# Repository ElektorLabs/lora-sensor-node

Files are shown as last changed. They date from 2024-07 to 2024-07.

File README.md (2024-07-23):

# Solar Powered LoRaWAN Sensor Node

## Overview

This project is a solar-powered LoRaWAN sensor node designed to monitor environmental conditions such as soil moisture, temperature, humidity, and CO2 levels. The node transmits data via LoRaWAN to The Things Network (TTN), and the data can be visualized using platforms like DataCake and Home Assistant.

## Repository Structure

- **src**: Contains the source code for the sensor node.
- **hardware**: Contains the schematic of the project along with CAD STL files for the Solar Panel and Component Enclosure and the Stevenson Enclosure for the SCD30 Sensor.

## Libraries Used

The following libraries, are used in this project:
- `SCD30` by [Seeed Studio](https://github.com/Seeed-Studio/Seeed_SCD30) 
- `HardwareSerial` - Built in Libaray

## Setup

### 1. Hardware Setup
- Assemble the hardware components as per the schematic provided in the hardware folder.
- Use the CAD STL files to 3D print the enclosures for the solar panel, component, and Stevenson enclosure for the SCD30 sensor. (Recommended 3D Printing Filament : PETG)

### 2. Software Setup
- Open the code from the `src` folder in your Arduino IDE.
- Configure the necessary parameters, such as the App Key, in the code.
- Upload the code to the SeeedStudio XIAO ESP32-C3 microcontroller.

### 3. Integrate with The Things Network (TTN)
- Register your device on the TTN console and obtain the necessary credentials (Device EUI, Application EUI, and App Key).
- Configure the payload format to match the data structure sent by the sensor node.
- Add a webhook for DataCake integration to visualize the data.
- You have to also add the custom javascript format for decoding the HEX code sent from the LoRa Device on to your TTN and DataCake Dashboard: 

```js
function Decoder(bytes, port) {
  var decoded = {};
  if (port === 8) {
    decoded.soilMoisture = (bytes[0] << 8) | bytes[1];
    decoded.temp = ((bytes[2] << 8) | bytes[3]);
    decoded.humi = (bytes[4] << 8) | bytes[5];
    decoded.co2 = (bytes[6] << 8) | bytes[7];
    decoded.battery = (bytes[8] << 8) | bytes[9];
  }
  return decoded;
}
```

### 4. Integrate with Home Assistant
- Generate an API Key in the TTN console.
- Add "The Things Network" integration in Home Assistant and enter the necessary credentials.
- Configure the sensor entities in the `configuration.yaml` file to define the units of measurement:

  ```yaml
  sensor.lora_sense_node_temperature:
    unit_of_measurement: "°C"
  sensor.lora_sense_node_co2:
    unit_of_measurement: "ppm"
  sensor.lora_sense_node_humidity:
    unit_of_measurement: "%"
  sensor.lora_sense_node_soilmoisture:
    unit_of_measurement: "%"
  ```

## Future Improvements

Future improvements to this project could include integrating an external RTC with a power latch circuit to reduce idle power consumption. Additionally, more sensors can be added to extend the functionality of the sensor node for various applications.

## License

This project is licensed under the MIT License - see the [LICENSE](LICENSE) file for details.

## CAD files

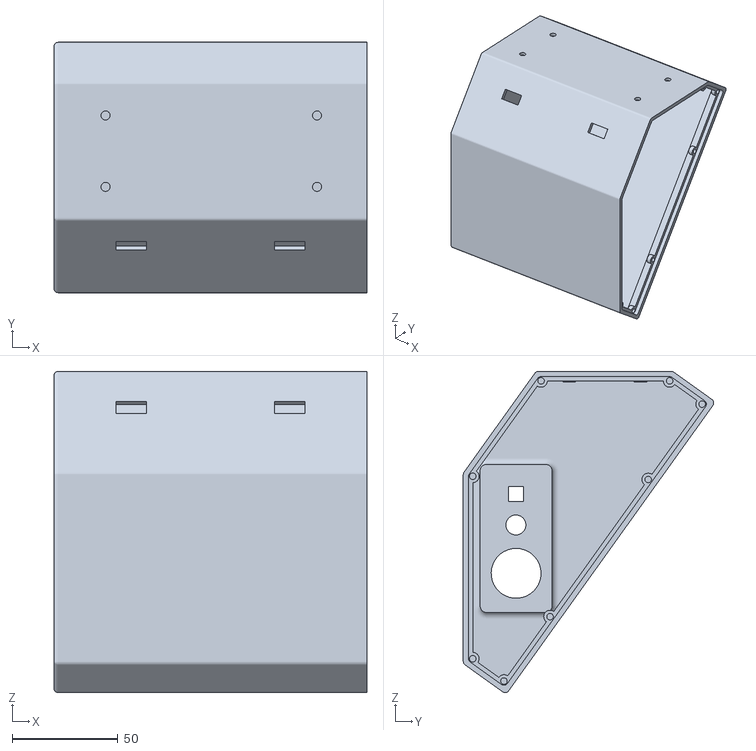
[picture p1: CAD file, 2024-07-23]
hardware/solarpanel holder enclosure/stl/asm_enclosure - enclosure_main-1-1.STL
148.0 x 118.5 x 151.9

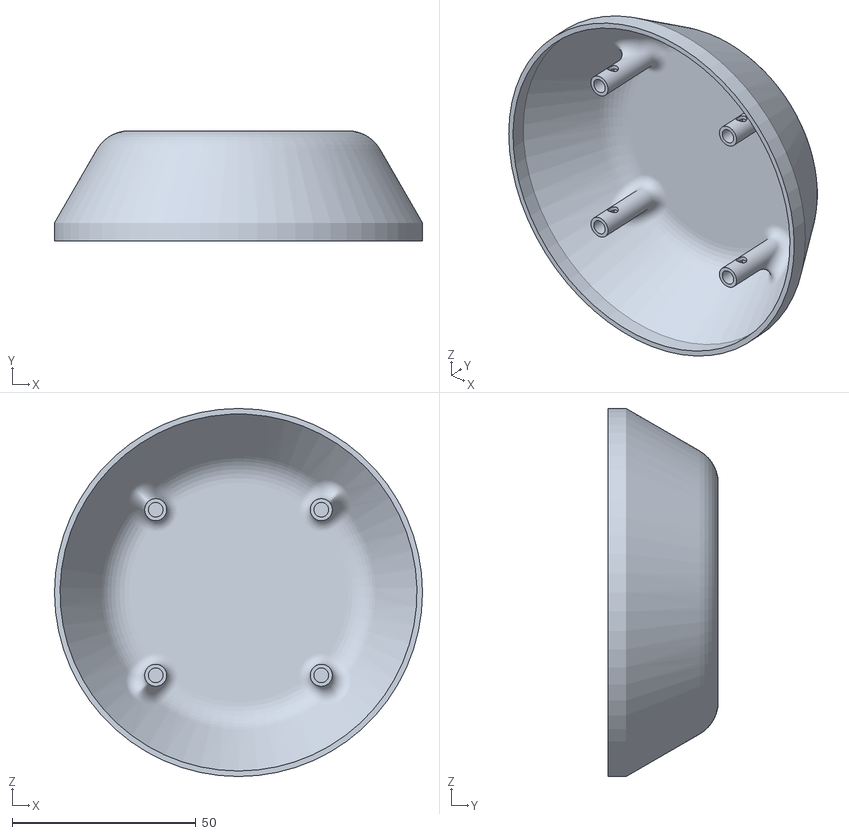
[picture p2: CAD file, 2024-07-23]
hardware/stevenson screen/stl/asm_stevemson-screen - TopCover-1.STL
100.0 x 30.0 x 100.0

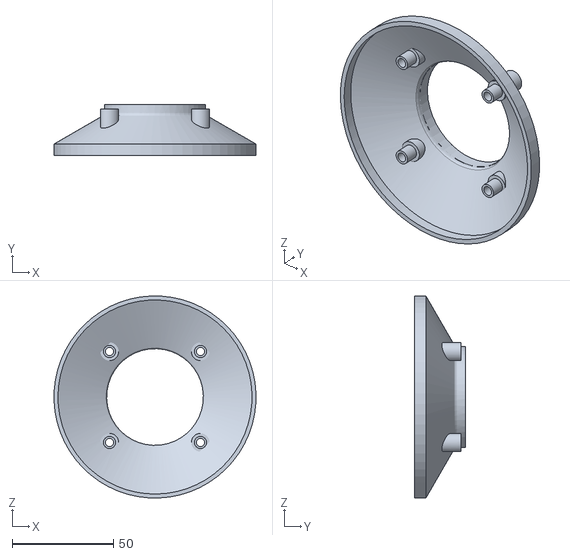
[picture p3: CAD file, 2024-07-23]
hardware/stevenson screen/stl/asm_stevemson-screen - Middle-5.STL
99.9 x 25.0 x 99.9

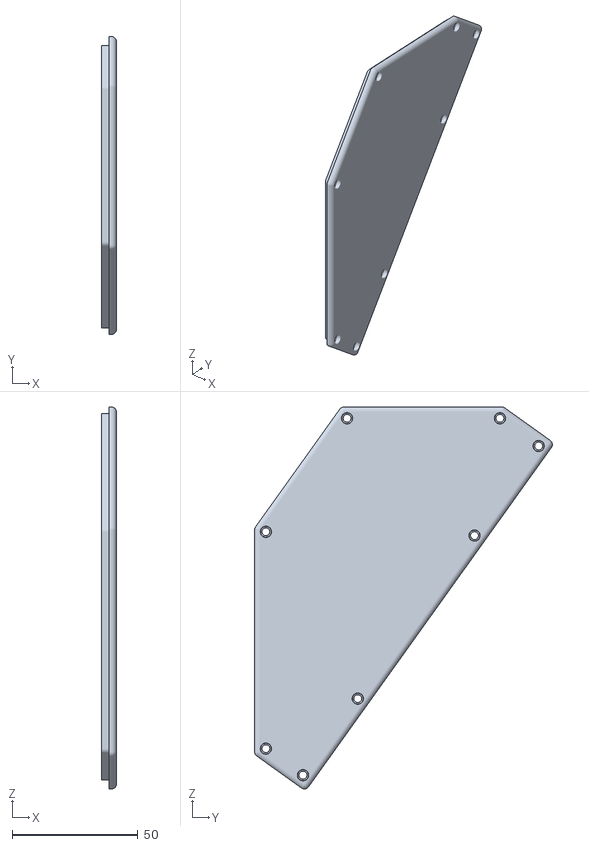
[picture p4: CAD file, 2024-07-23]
hardware/solarpanel holder enclosure/stl/asm_enclosure - side_panel-1-1.STL
6.00 x 118.5 x 151.9

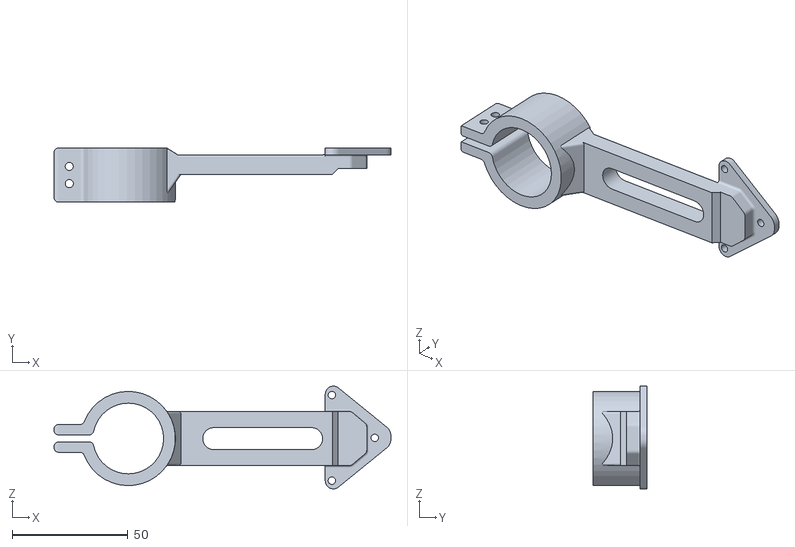
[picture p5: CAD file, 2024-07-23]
hardware/stevenson screen/stl/asm_stevemson-screen - mount_holder-1.STL
145.3 x 23.4 x 44.3

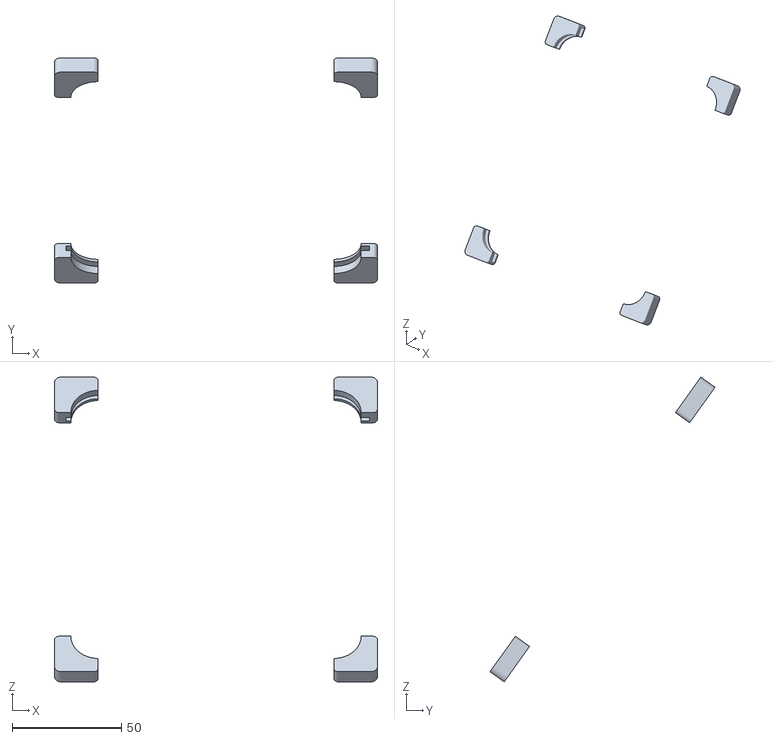
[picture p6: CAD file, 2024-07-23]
hardware/solarpanel holder enclosure/stl/asm_enclosure - solarpanel-holders-1-1.STL
148.0 x 103.1 x 139.6

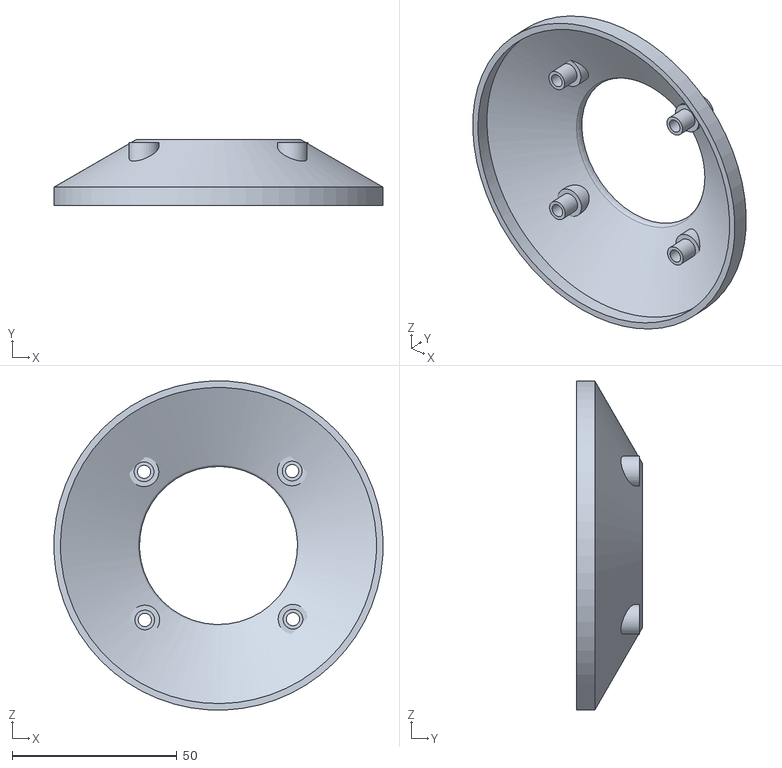
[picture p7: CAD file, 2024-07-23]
hardware/stevenson screen/stl/asm_stevemson-screen - bottom-1.STL
99.9 x 20.0 x 99.9

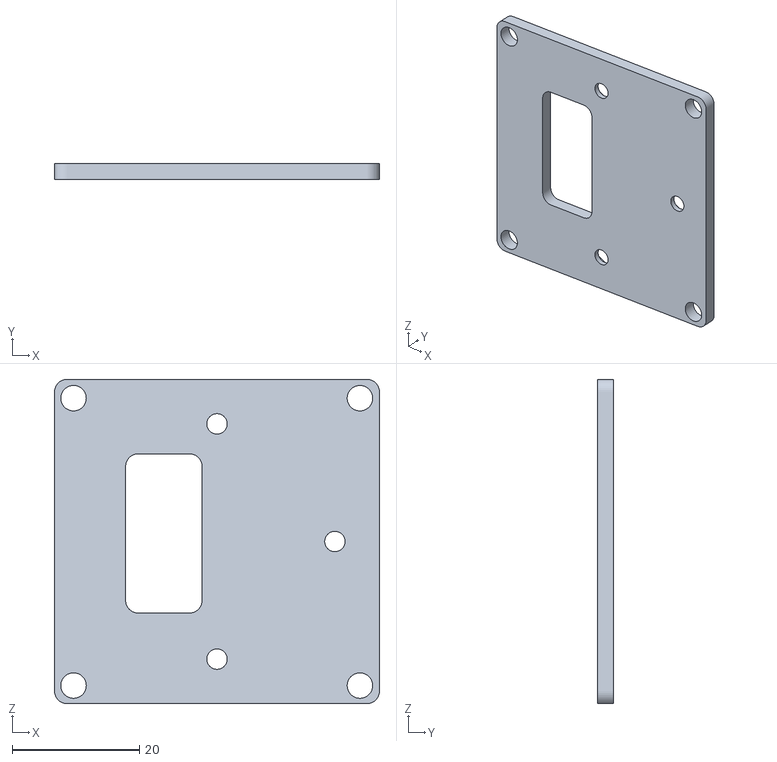
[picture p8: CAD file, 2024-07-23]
hardware/stevenson screen/stl/asm_stevemson-screen - Bottom Mount-1.STL
51.0 x 2.50 x 50.9

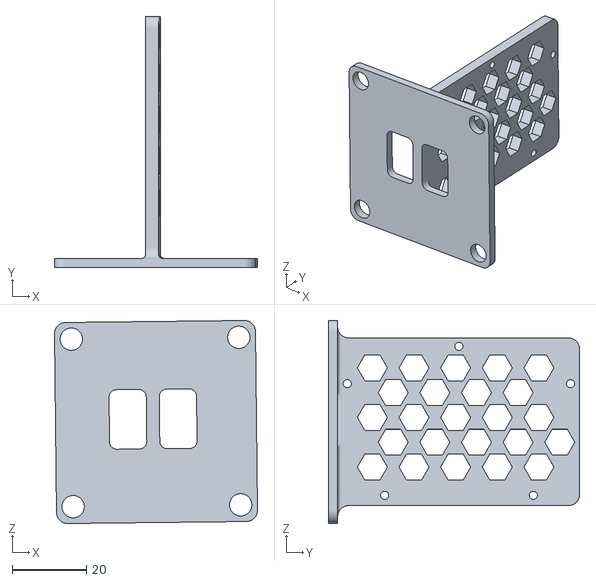
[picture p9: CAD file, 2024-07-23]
hardware/stevenson screen/stl/asm_stevemson-screen - component_holder-1.STL
54.5 x 67.5 x 54.5

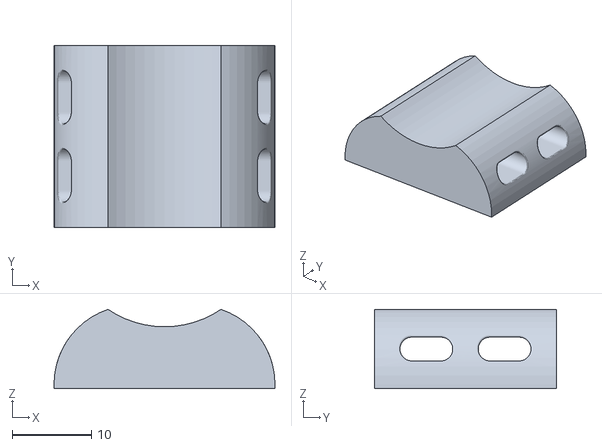
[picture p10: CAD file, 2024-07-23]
hardware/solarpanel holder enclosure/stl/ziptie-holder.STL
27.9 x 23.0 x 10.0

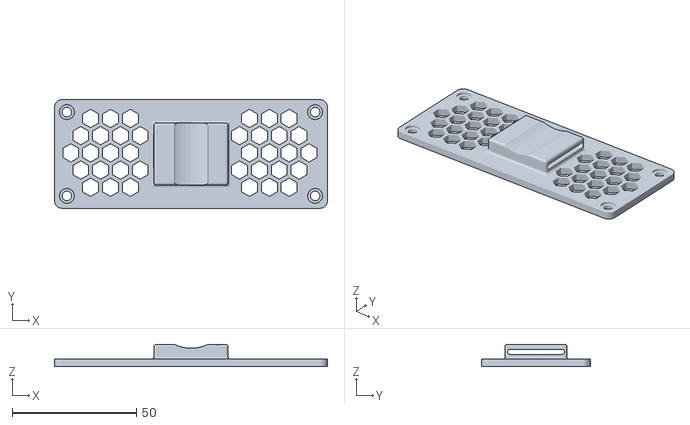
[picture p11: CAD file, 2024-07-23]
hardware/solarpanel holder enclosure/stl/back_mount.STL
110.0 x 43.8 x 9.00

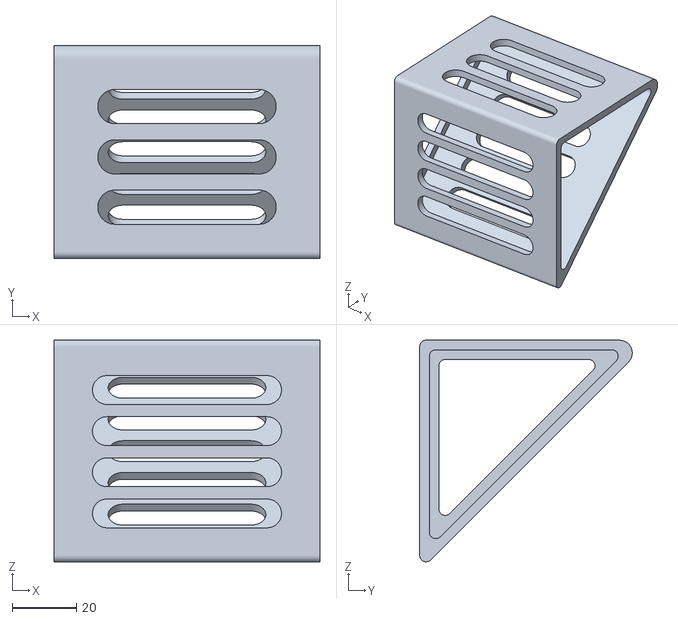
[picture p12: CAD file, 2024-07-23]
hardware/solarpanel holder enclosure/stl/components-pack.STL
83.0 x 66.3 x 69.2

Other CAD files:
hardware/stevenson screen/stl/asm_stevemson-screen - Middle-8.STL
hardware/stevenson screen/stl/asm_stevemson-screen - Middle-7.STL
hardware/stevenson screen/stl/asm_stevemson-screen - Middle-6.STL

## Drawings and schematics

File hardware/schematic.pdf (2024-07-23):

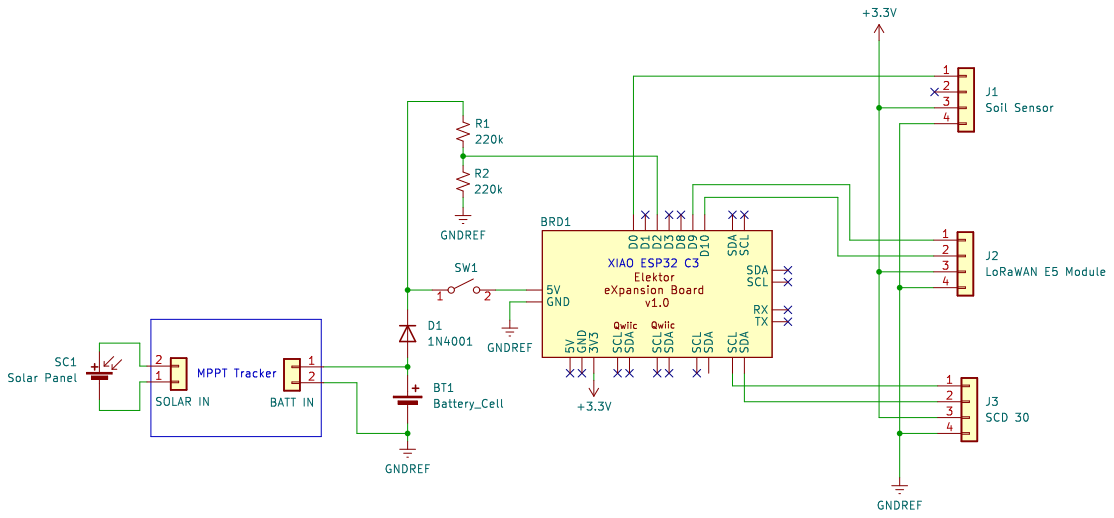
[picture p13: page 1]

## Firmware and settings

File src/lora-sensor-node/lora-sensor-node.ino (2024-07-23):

#include <Arduino.h>
#include <SCD30.h>
#include <HardwareSerial.h>
#include <config.ino>

//Defining Hardware the second internal UART - Serial2 for the LoRaWAN E5 Module- Pin 9 and 10.
HardwareSerial Serial2(1);

int soilSensor = A1;
int soilSensorValue = 0;
int soilMoisturePercent = 0;

int batterySensor = A2;
int batterySensorValue = 0;


float temp = 0;
float humi = 0;
float co2 = 0;
float battery = 0;

static char recv_buf[512];
static bool is_exist = false;
static bool is_join = false;
static int led = 0;

void setup() {

  Serial.begin(115200);
  Wire.begin();

  scd30.initialize();
  scd30.setAutoSelfCalibration(1);
  // And configure Serial2 on pins RX=D9, TX=D10
  Serial2.begin(9600, SERIAL_8N1, TX_2, RX_2);
  Serial2.print("Serial2");

  Serial2.begin(9600);

  if (at_send_check_response("+AT: OK", 100, "AT\r\n")) {
    is_exist = true;
    at_send_check_response("+ID: AppEui", 1000, "AT+ID\r\n");
    at_send_check_response("+MODE: LWOTAA", 1000, "AT+MODE=LWOTAA\r\n");
    at_send_check_response("+DR: EU868", 1000, "AT+DR=EU868\r\n");
    at_send_check_response("+CH: NUM", 1000, "AT+CH=NUM,0-2\r\n");
    at_send_check_response("+KEY: APPKEY", 1000, "AT+KEY=APPKEY,\"C2XXXXXXXXXXXXXXXXXXXXXXXXXXXXXXXXX\"\r\n");  // Enter your generated APP Key here. [This is generated on add device page, at Things Network Platfrom]
    at_send_check_response("+CLASS: C", 1000, "AT+CLASS=A\r\n");
    at_send_check_response("+PORT: 8", 1000, "AT+PORT=8\r\n");
    delay(200);
    Serial.println("LoRaWAN");
    is_join = true;
  } else {
    is_exist = false;
    Serial.print("No LoRa E5 module found.\r\n");
  }
}

void loop() {

  // When runing deep sleep mode we dont need timers to execute the command as the controller will wake up after 10 mins to excute the code.
  getSensors();
  sendData();
  // Configure the wake-up source and duration for deep sleep
  esp_sleep_enable_timer_wakeup(10 * 60 * 1000000); // 10 minutes in microseconds
  // Enter deep sleep mode
  esp_deep_sleep_start();
}

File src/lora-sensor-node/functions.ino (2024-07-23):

// Function to send an AT command and check for a specific response

static int at_send_check_response(char *p_ack, int timeout_ms, char *p_cmd, ...) {
  int ch;
  int num = 0;
  int index = 0;
  int startMillis = 0;
  va_list args;
  memset(recv_buf, 0, sizeof(recv_buf));  // Clear the receive buffer
  va_start(args, p_cmd);
  Serial2.printf(p_cmd, args);  // Send command to LoRa module
  Serial.printf(p_cmd, args);   // Print command to serial monitor
  va_end(args);
  delay(200);
  startMillis = millis();

  if (p_ack == NULL) {
    return 0;  // Return if no acknowledgment string is provided
  }

  do {
    while (Serial2.available() > 0) {
      ch = Serial2.read();     // Read character from LoRa module
      recv_buf[index++] = ch;  // Store character in receive buffer
      Serial.print((char)ch);  // Print character to serial monitor
      delay(2);
    }

    if (strstr(recv_buf, p_ack) != NULL) {
      return 1;  // Return success if acknowledgment is found
    }

  } while (millis() - startMillis < timeout_ms);
  return 0;  // Return failure if timeout is reached
}

// Function to parse received messages from the LoRa module
static void recv_prase(char *p_msg) {
  if (p_msg == NULL) {
    return;
  }
  char *p_start = NULL;
  int data = 0;
  int rssi = 0;
  int snr = 0;

  p_start = strstr(p_msg, "RX");
  if (p_start && (1 == sscanf(p_start, "RX: \"%d\"\r\n", &data))) {
    Serial.println(data);
    led = !!data;
    if (led) {
      digitalWrite(LED_BUILTIN, LOW);  // Turn on LED if data received - Not used on hardware for power effiency
    } else {
      digitalWrite(LED_BUILTIN, HIGH);  // Turn off LED otherwise - Not used on hardware for power effiency
    }
  }

  p_start = strstr(p_msg, "RSSI");
  if (p_start && (1 == sscanf(p_start, "RSSI %d,", &rssi))) {
    Serial.print(rssi);  // Print RSSI value
  }
  p_start = strstr(p_msg, "SNR");
  if (p_start && (1 == sscanf(p_start, "SNR %d", &snr))) {
    Serial.print("snr :");
    Serial.println(snr);  // Print SNR value
  }
}



void getSensors() {

  for (int i = 0; i < 4; i++) {

    soilSensorValue = analogRead(soilSensor);                     // Read soil moisture sensor
    soilMoisturePercent = map(soilSensorValue, 0, 4095, 0, 100);  // Convert to percentage

    float result[3] = { 0 };

    if (scd30.isAvailable()) {
      scd30.getCarbonDioxideConcentration(result);  // Read SCD30 sensor values
      Serial.print("Carbon Dioxide Concentration is: ");
      Serial.print(result[0]);
      Serial.println(" ppm");

      Serial.print("Temperature = ");
      Serial.print(result[1]);
      Serial.println(" ℃");

      Serial.print("Humidity = ");
      Serial.print(result[2]);
      Serial.println(" %");
      Serial.println(" ");

      temp = result[1];
      humi = result[2];
      co2 = result[0];
    }
    vTaskDelay(1000);  // Delay to allow sensor stabilization
  }

  scd30.stopMeasurement();  // Stops SCD30 from making measurement for power saving.


  float total_voltage = 0;
  // Take 20 readings for the battery voltage and average them
  for (int i = 0; i < 20; i++) {
    batterySensorValue = analogReadMilliVolts(batterySensor);
    float actual_voltage = ((batterySensorValue * ((R1 + R2) / R2))) / 1000;
    total_voltage += actual_voltage;
  }

  float average_voltage = total_voltage / 20;
  battery = (average_voltage / 4.3) * 100; // Calculate battery percentage
  Serial.print("Battery = ");
  Serial.println(battery);
}


// Function to send data over LoRa
void sendData() {

  if (is_exist) {

    int ret = 0;

    if (is_join) {

      // Send an AT command to join the LoRa network and check the response
      ret = at_send_check_response("+JOIN: Network joined", 12000, "AT+JOIN\r\n");

      // Prepare and send the sensor data as a hexadecimal string via LoRa
      char cmd[128];
      sprintf(cmd, "AT+CMSGHEX=\"%04X%04X%04X%04X%04X\"\r\n", (int)soilMoisturePercent, (int)temp, (int)humi, (int)co2, (int)battery);
      ret = at_send_check_response("Done", 5000, cmd);

      // Check if data was sent successfully and process the response
      if (ret) {
        recv_prase(recv_buf);  // Parse received message if data sent successfully
      } else {
        Serial.print("Send failed!\r\n\r\n"); // Print error message if sending failed
      }
    }
  }
  // Put LoRa module to sleep mode to save power
  at_send_check_response("+AT: OK", 100, "AT+LOWPOWER\r\n");  // Puts LoRa Module to sleep mode - reduces current from 7.82mA to 51.7uA
}
